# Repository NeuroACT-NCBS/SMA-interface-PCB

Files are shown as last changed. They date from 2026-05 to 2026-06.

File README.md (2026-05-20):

# SMA Interface PCB

KiCad PCB design for a reward-well controller for behavioral neuroscience experiments.

## Function

Built around an **RP2040-Zero** microcontroller. Takes 6 SMA coaxial sensor inputs from the spikegadgets ECU, through a schmitt-trigger buffer, and drives 4 TMC2209 stepper motors for reward dispensing. 8× AO3400A MOSFETs switch light and sounds. Two stacked USB-A ports allow to connect with the reward wells.

## Requirements

- [KiCad](https://www.kicad.org/) 10.0+

Clone with `--recurse-submodules` to pull the [NeuroACT-KiCad-libraries](https://github.com/NeuroACT-NCBS/NeuroACT-KiCad-libraries) automatically:

```bash
git clone --recurse-submodules https://github.com/NeuroACT-NCBS/SMA-interface-pcb.git
```

## KiCad Plugins

- **Fabrication Toolkit** — for generating production Gerber files
- **Round Tracks** — configured via `.round-tracks-config`

## License

CERN Open Hardware Licence Version 2 — see [LICENSE](LICENSE)

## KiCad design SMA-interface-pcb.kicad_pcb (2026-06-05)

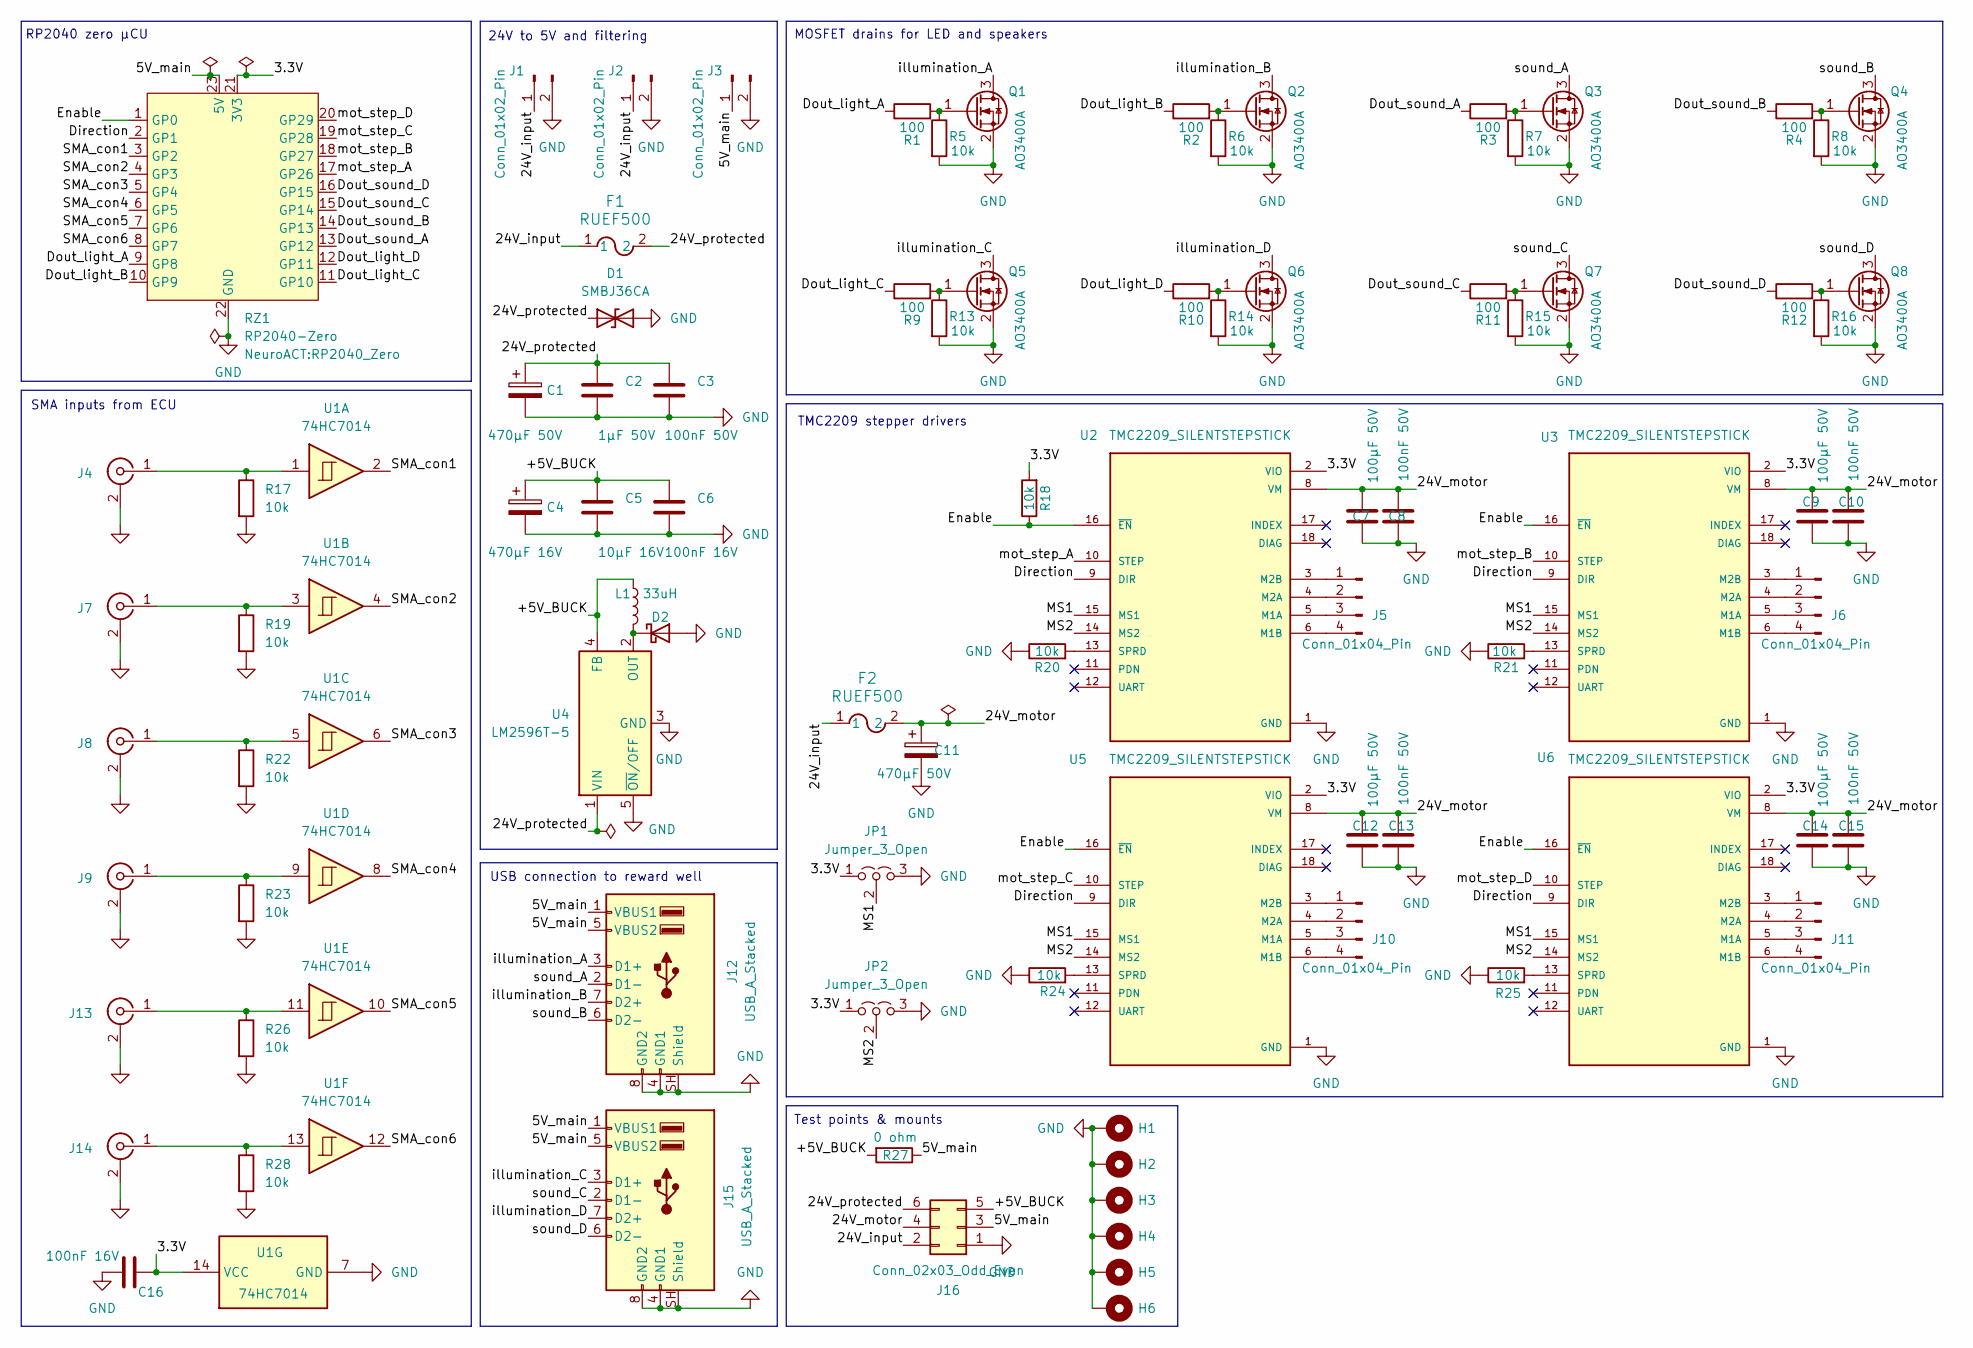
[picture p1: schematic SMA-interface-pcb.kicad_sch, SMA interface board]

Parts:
C1, C11: 470µF 50V; CP_Radial_D10.0mm_P5.00mm
C2: 1µF 50V; C_1206_3216Metric_Pad1.33x1.80mm_HandSolder
C3, C8, C10, C13, C15: 100nF 50V; C_1206_3216Metric_Pad1.33x1.80mm_HandSolder
C4: 470µF 16V; CP_Radial_D8.0mm_P5.00mm
C5: 10µF 16V; C_1206_3216Metric_Pad1.33x1.80mm_HandSolder
C6, C16: 100nF 16V; C_1206_3216Metric_Pad1.33x1.80mm_HandSolder
C7, C9, C12, C14: 100µF 50V; CP_Radial_horizontal_D8.0mm_P3.50mm
D1: SMBJ36CA; D_SMA-SMB_Universal_Handsoldering
D2: SR5100; D_DO-201AD_P15.24mm_Horizontal
F1, F2: RUEF500; FUSE_RUEF500_LTF
H1, H2, H3, H4, H5, H6: MountingHole; MountingHole_3.2mm_M3_DIN965_Pad_TopBottom
J1, J2, J3: Conn_01x02_Pin; Molex_Mini-Fit_Jr_5569-02A2_2x01_P4.20mm_Horizontal
J4, J7, J8, J9, J13, J14: Conn_Coaxial; SMA_Amphenol_901-143_Horizontal
J5, J6, J10, J11: Conn_01x04_Pin; PinHeader_1x04_P2.54mm_Vertical
J12, J15: USB_A_Stacked; USB_A_Wuerth_61400826021_Horizontal_Stacked
J16: Conn_02x03_Odd_Even; PinSocket_2x03_P2.54mm_Vertical
JP1, JP2: Jumper_3_Open; PinHeader_1x03_P2.54mm_Vertical
L1: 33uH; L_Toroid_Vertical_L16.0mm_W8.0mm_P7.62mm
Q1, Q2, Q3, Q4, Q5, Q6, Q7, Q8: AO3400A; SOT-23
R1, R2, R3, R4, R9, R10, R11, R12: 100; R_1206_3216Metric_Pad1.30x1.75mm_HandSolder
R5, R6, R7, R8, R13, R14, R15, R16, R17, R18, R19, R20, R21, R22, R23, R24, R25, R26, R28: 10k; R_1206_3216Metric_Pad1.30x1.75mm_HandSolder
R27: 0 ohm; R_1206_3216Metric_Pad1.30x1.75mm_HandSolder
RZ1: RP2040-Zero; RP2040_Zero
U1: 74HC7014; SOIC-14_3.9x8.7mm_P1.27mm
U2, U3, U5, U6: TMC2209_SILENTSTEPSTICK; MODULE_TMC2209_SILENTSTEPSTICK; PARTREV 1.20
U4: LM2596T-5; TO-220-5_Vertical

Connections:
/3.3V: C16.2, JP1.1 (A), JP2.1 (A), R18.2, RZ1.21 (3V3), U1.14 (VCC), U2.2 (VIO), U3.2 (VIO), U5.2 (VIO), U6.2 (VIO)
/5V_main: J3.1, J12.1 (VBUS1), J12.5 (VBUS2), J15.1 (VBUS1), J15.5 (VBUS2), J16.3, R27.1, RZ1.23 (5V)
/24V_input: F1.1, F2.1, J1.1, J2.1, J16.2
/24V_motor: C7.1, C8.1, C9.1, C10.1, C11.1, C12.1, C13.1, C14.1, C15.1, F2.2, J16.4, U2.8 (VM), U3.8 (VM), U5.8 (VM), U6.8 (VM)
/24V_protected: C1.1, C2.1, C3.1, D1.1 (A1), F1.2, J16.6, U4.1 (VIN)
/+5V_BUCK: C4.1, C5.1, C6.1, J16.5, L1.2, R27.2, U4.4 (FB)
/Direction: RZ1.2 (GP1), U2.9 (DIR), U3.9 (DIR), U5.9 (DIR), U6.9 (DIR)
/Dout_light_A: R1.1, RZ1.9 (GP8)
/Dout_light_B: R2.1, RZ1.10 (GP9)
/Dout_light_C: R9.1, RZ1.11 (GP10)
/Dout_light_D: R10.1, RZ1.12 (GP11)
/Dout_sound_A: R3.1, RZ1.13 (GP12)
/Dout_sound_B: R4.1, RZ1.14 (GP13)
/Dout_sound_C: R11.1, RZ1.15 (GP14)
/Dout_sound_D: R12.1, RZ1.16 (GP15)
/Enable: R18.1, RZ1.1 (GP0), U2.16 (~EN), U3.16 (~EN), U5.16 (~EN), U6.16 (~EN)
/MS1: JP1.2 (C), U2.15 (MS1), U3.15 (MS1), U5.15 (MS1), U6.15 (MS1)
/MS2: JP2.2 (C), U2.14 (MS2), U3.14 (MS2), U5.14 (MS2), U6.14 (MS2)
/SMA_con1: RZ1.3 (GP2), U1.2
/SMA_con2: RZ1.4 (GP3), U1.4
/SMA_con3: RZ1.5 (GP4), U1.6
/SMA_con4: RZ1.6 (GP5), U1.8
/SMA_con5: RZ1.7 (GP6), U1.10
/SMA_con6: RZ1.8 (GP7), U1.12
/illumination_A: J12.3 (D1+), Q1.3 (D)
/illumination_B: J12.7 (D2+), Q2.3 (D)
/illumination_C: J15.3 (D1+), Q5.3 (D)
/illumination_D: J15.7 (D2+), Q6.3 (D)
/mot_step_A: RZ1.17 (GP26), U2.10 (STEP)
/mot_step_B: RZ1.18 (GP27), U3.10 (STEP)
/mot_step_C: RZ1.19 (GP28), U5.10 (STEP)
/mot_step_D: RZ1.20 (GP29), U6.10 (STEP)
/sound_A: J12.2 (D1-), Q3.3 (D)
/sound_B: J12.6 (D2-), Q4.3 (D)
/sound_C: J15.2 (D1-), Q7.3 (D)
/sound_D: J15.6 (D2-), Q8.3 (D)
GND: C1.2, C2.2, C3.2, C4.2, C5.2, C6.2, C7.2, C8.2, C9.2, C10.2, C11.2, C12.2, C13.2, C14.2, C15.2, C16.1, D1.2 (A2), D2.2 (A), H1.1 (1_1), H2.1 (1_1), H3.1 (1_1), H4.1 (1_1), H5.1 (1_1), H6.1 (1_1), J1.2, J2.2, J3.2, J4.2 (Ext), J7.2 (Ext), J8.2 (Ext), J9.2 (Ext), J12.4 (GND1), J12.8 (GND2), J12.SH (Shield), J13.2 (Ext), J14.2 (Ext), J15.4 (GND1), J15.8 (GND2), J15.SH (Shield), J16.1, JP1.3 (B), JP2.3 (B), Q1.2 (S), Q2.2 (S), Q3.2 (S), Q4.2 (S), Q5.2 (S), Q6.2 (S), Q7.2 (S), Q8.2 (S), R5.2, R6.2, R7.2, R8.2, R13.2, R14.2, R15.2, R16.2, R17.2, R19.2, R20.1, R21.1, R22.2, R23.2, R24.1, R25.1, R26.2, R28.2, RZ1.22 (GND), U1.7 (GND), U2.1 (GND), U2.7 (GND), U3.1 (GND), U3.7 (GND), U4.3 (GND), U4.5 (~ON/OFF), U5.1 (GND), U5.7 (GND), U6.1 (GND), U6.7 (GND)
unnamed: D2.1 (K), L1.1, U4.2 (OUT)
unnamed: J4.1 (In), R17.1, U1.1
unnamed: J5.1, U2.3 (M2B)
unnamed: J5.2, U2.4 (M2A)
unnamed: J5.3, U2.5 (M1A)
unnamed: J5.4, U2.6 (M1B)
unnamed: J6.1, U3.3 (M2B)
unnamed: J6.2, U3.4 (M2A)
unnamed: J6.3, U3.5 (M1A)
unnamed: J6.4, U3.6 (M1B)
unnamed: J7.1 (In), R19.1, U1.3
unnamed: J8.1 (In), R22.1, U1.5
unnamed: J9.1 (In), R23.1, U1.9
unnamed: J10.1, U5.3 (M2B)
unnamed: J10.2, U5.4 (M2A)
unnamed: J10.3, U5.5 (M1A)
unnamed: J10.4, U5.6 (M1B)
unnamed: J11.1, U6.3 (M2B)
unnamed: J11.2, U6.4 (M2A)
unnamed: J11.3, U6.5 (M1A)
unnamed: J11.4, U6.6 (M1B)
unnamed: J13.1 (In), R26.1, U1.11
unnamed: J14.1 (In), R28.1, U1.13
unnamed: Q1.1 (G), R1.2, R5.1
unnamed: Q2.1 (G), R2.2, R6.1
unnamed: Q3.1 (G), R3.2, R7.1
unnamed: Q4.1 (G), R4.2, R8.1
unnamed: Q5.1 (G), R9.2, R13.1
unnamed: Q6.1 (G), R10.2, R14.1
unnamed: Q7.1 (G), R11.2, R15.1
unnamed: Q8.1 (G), R12.2, R16.1
unnamed: R20.2, U2.13 (SPRD)
unnamed: R21.2, U3.13 (SPRD)
unnamed: R24.2, U5.13 (SPRD)
unnamed: R25.2, U6.13 (SPRD)

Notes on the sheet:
MOSFET drains for LED and speakers
24V to 5V and filtering
SMA inputs from ECU
TMC2209 stepper drivers
USB connection to reward well
Test points & mounts
RP2040 zero µCU

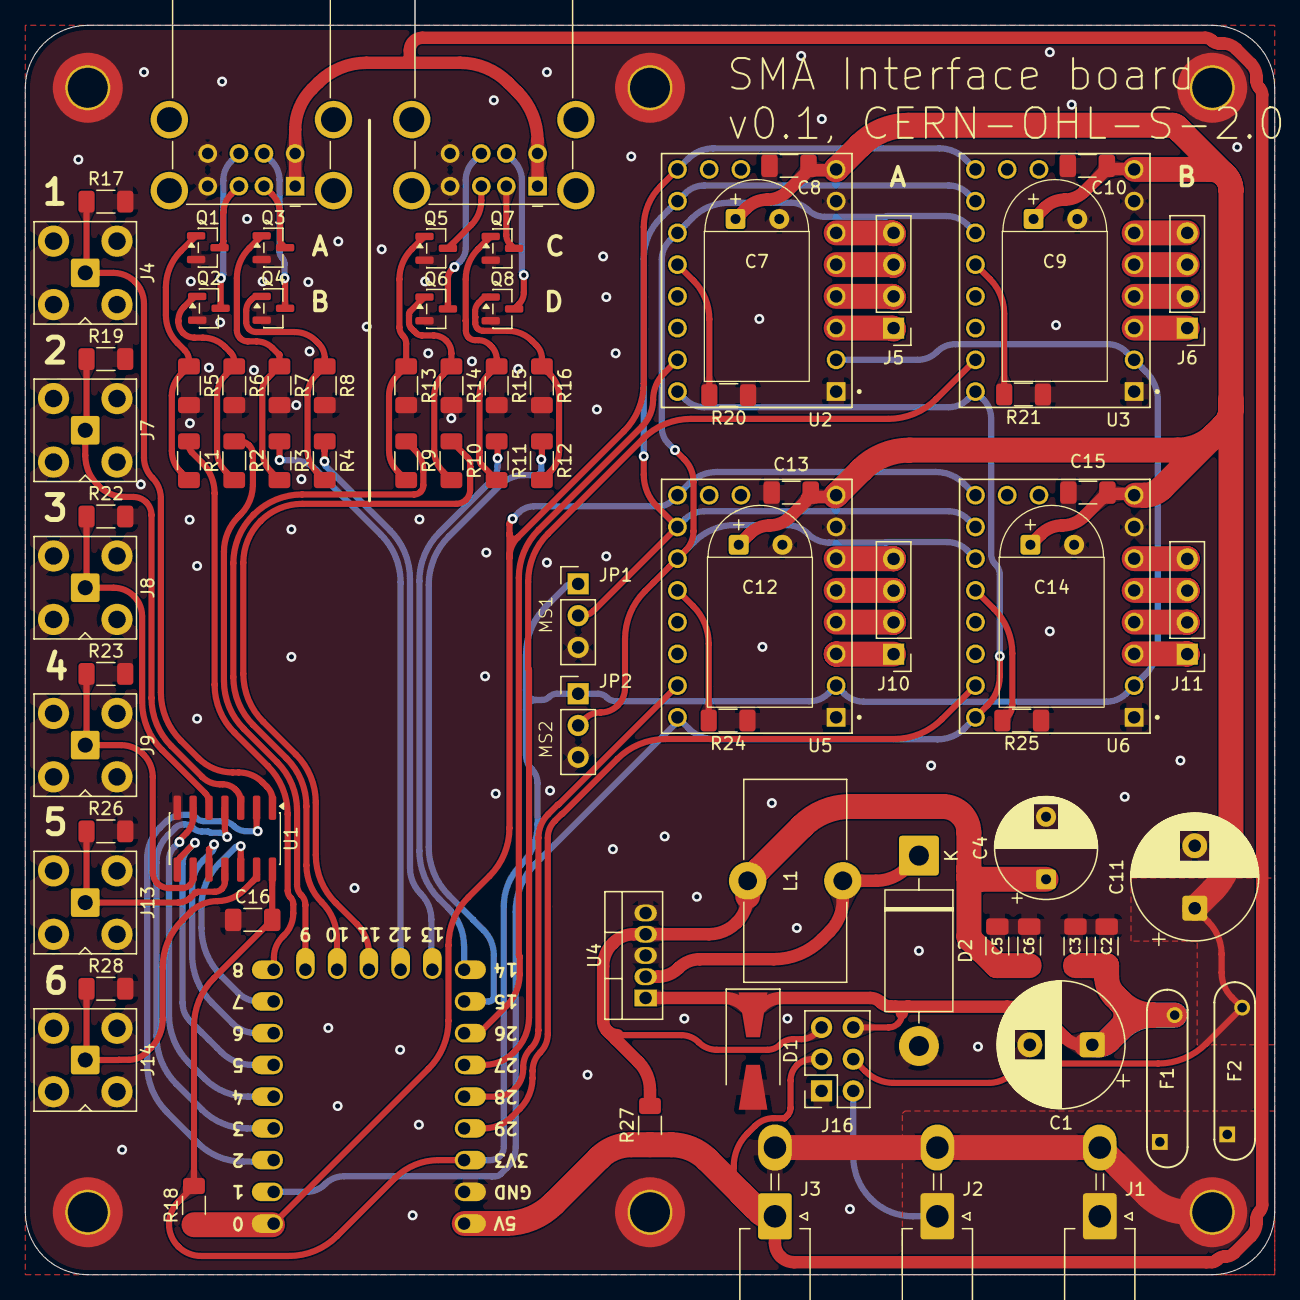
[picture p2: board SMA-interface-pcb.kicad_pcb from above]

Board: 2 copper layers, 100.0 x 100.0 mm, 88 parts (0 on the bottom side), 72 nets.

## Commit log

2025-06-25 Init project for SMA port of Behaviour arena PCBs
    [usbC_power_controller.kicad_pcb, usbC_power_controller.kicad_sch]
2025-12-10 first prototype of a working sma board
    [usbC_power_controller.kicad_pcb, usbC_power_controller.kicad_sch]
2025-12-11 updated power distribution board
    [usbC_power_controller.kicad_pcb, usbC_power_controller.kicad_sch]
2026-03-10 rename project to SMA-interface-pcb after splitting monorepo
    Split from the Behaviour-arena-PCBs monorepo into its own
    standalone repository. Renamed all project files from
    usbC_power_controller to SMA-interface-pcb via KiCad Save As.
    [SMA-interface-pcb.kicad_pcb, SMA-interface-pcb.kicad_sch]
2026-03-10 add NeuroACT-KiCad-libraries as submodule
2026-03-10 replace TRODES_SMA with KIPRJMOD path in PCB 3D model reference
    [SMA-interface-pcb.kicad_pcb]
2026-05-18 updated schematic to v0
    [SMA-interface-pcb.kicad_pcb, SMA-interface-pcb.kicad_sch]
2026-05-20 updated schematic with appropriate symbols, incomplete
    [SMA-interface-pcb.kicad_sch]
2026-05-27 updated schematic with appropriate symbols, to be verified
    [SMA-interface-pcb.kicad_pcb, SMA-interface-pcb.kicad_sch]
2026-05-30 first round of routing done
    [SMA-interface-pcb.kicad_pcb, SMA-interface-pcb.kicad_sch]
2026-06-04 footprint placement V1
    [SMA-interface-pcb.kicad_pcb, SMA-interface-pcb.kicad_sch]
2026-06-05 rounded tracks, updated Library
    [SMA-interface-pcb.kicad_pcb]
